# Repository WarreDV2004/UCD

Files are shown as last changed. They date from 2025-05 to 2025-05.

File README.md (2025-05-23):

# VibeLink
*Kotstudenten gemakkelijker laten communiceren met mede kotstudenten.* 

*Projectteam: Cezar Herbots; Warre De Vriendt*

Datum: 22/05/2025

## Samenvatting

Kotstudenten komen vaak toe op kot zonder iemand te kennen. Velen durven andere studenten niet snel aan te spreken en zo kunnen ze zich na een tijd eenzaam voelen. De oplossingen hiervoor is VibeLink een product dat niet alleen sfeer toevoegt aan je kot, maar vooral op een laagdrempelige manier je gevoel kan weergeven en overbrengen naar de medekotstudenten. Hiermee kunnen andere studenten jouw mood zien en jij hun mood.

"VibeLink moet studenten op het juiste moment een subtiel duwtje geven om verbinding te maken, zonder frictie of sociale druk."

<div align="center">

<table>
  <tr>
    <td rowspan="2">
      
    </td>
    <td>
      
    </td>
  </tr>
  <tr>
    <td>
      
    </td>
  </tr>
</table>

</div>

## Introductie

In veel studentenkoten is de inrichting gericht op individuele kamers en privacy, wat er vaak toe leidt dat studenten elkaar minder spontaan ontmoeten of met elkaar in contact komen. Dit blijkt ook uit verschillende artikelen. Met VibeLink willen we de sociale drempel verlagen en studenten stimuleren om vaker met elkaar te communiceren.

De kernfunctie van VibeLink is het delen van gemoedstoestanden en intenties met medebewoners. Studenten kunnen eenvoudig aangeven hoe ze zich voelen of waar ze zin in hebben, met opties zoals:

- Samen koken
- Samen sporten
- Iets gaan drinken
- Niet storen / slaapstand
- Nerveus
- Blij
- Verdrietig

De gebruiker behoudt hierbij volledige controle over wanneer en welke mood hij of zij deelt met anderen.

Naast deze communicatiefunctie is VibeLink gekoppeld aan een slimme lamp, die de gebruiker kan plaatsen in een armatuur naar keuze. Deze lamp vergroot de zichtbaarheid en het gebruik van het systeem, en zorgt voor een visuele indicatie wanneer er een "match" is — wanneer iemand anders zich in dezelfde mood bevindt.

De bediening gebeurt via één draai-/drukknop, geïnspireerd op het bedieningsprincipe van de Google Nest Thermostaat. Hiermee kan de gebruiker:

- Een mood selecteren
- De slimme verlichting aanpassen
- Instellingen wijzigen

Op het scherm van de VibeLink wordt duidelijk weergegeven welke moods andere kotgenoten momenteel hebben gedeeld, waardoor het makkelijker wordt om contact te leggen of initiatief te nemen.

> [!Note]
> - Volledige protocollen en reports zijn beschikbaar onderaan de pagina bij [bijlagen](https://github.com/WarreDV2004/UCD/edit/main/README.md#bijlagen).
> - Ruwe data zoals foto's en notities zijn terug te vinden in de protocollen en reports.
> - Alle geraadpleegde bronnen zijn beschikbaar onderaan de pagina bij [bronnen](https://github.com/WarreDV2004/UCD/edit/main/README.md#bronnen).
> - Code en CAD modellen zijn terug te vinden in de desbetreffende mappen.

## Methodologie

Het proces startte met een verkennende fase, waarin de probleemstelling kritisch werd onderzocht. Centrale vragen waren: Wat is het probleem? Is het daadwerkelijk een probleem? En in hoeverre kan dit onderbouwd worden met bestaand of nieuw onderzoek? Na een herdefiniëring van de oorspronkelijke opdracht (“Rip the Brief”) werd de volgende design challenge geformuleerd:
Hoe kunnen slimme producten ingezet worden om emoties tussen kotstudenten op een laagdrempelige manier met elkaar te communiceren?

Tijdens de ontdekkingsfase werd onderzoek verricht naar het thema eenzaamheid onder studenten. Literatuurstudie en enquêtes onder kotstudenten gaven inzicht in de schaal en relevantie van het probleem, zowel algemeen als binnen de directe doelgroep. De resultaten bevestigden dat sociale isolatie op kot een herkenbaar en actueel probleem vormt. Deze bevindingen dienden als basis voor het definiëren van een gerichte ontwerpuitdaging.

Aan de hand van een full day sprint werden verschillende oplossingsrichtingen gegenereerd. Deze concepten zijn geëvalueerd op haalbaarheid, impact en gebruiksvriendelijkheid. Op basis van deze analyse werd één concept geselecteerd voor verdere uitwerking.

In de definitiefase werd onderzocht welke aanvullende functies het product kon bevatten om de betrokkenheid te verhogen. Een voorbeeld hiervan is de koppeling met een slimme lamp, die zowel de zichtbaarheid als het gebruik stimuleert. Daarnaast werden diverse interactie- en bedieningsmodellen onderzocht om tot de meest intuïtieve gebruikerservaring te komen.

De ontwikkelfase bestond uit drie delen, telkens met een specifieke focus op een vorm van ergonomie:

Develop 1: Fysieke en sensoriële ergonomie, getest via Wizard of Oz-methodes en touch and feel-materialen.

Develop 2: Integratie in het dagelijkse leven van studenten, onderzocht aan de hand van storyboards en contextuele toepassingen. Integratie in de gebouwen, interviews met verhuurders.

Develop 3: Cognitieve en deels sensoriële ergonomie, met nadruk op interfaceontwerp en gebruikslogica.

Elke fase droeg bij aan de ontwikkeling van een functioneel en gebruiksvriendelijk prototype dat gericht is op het versterken van sociale verbondenheid binnen studentenomgevingen.

Op het einde volgt de delivery en de eindpresentatie van het proces.

Afbeelding 2

## Discovery

### Doelstellingen

Tijdens deze ontdekkingsfase proberen we een helder beeld te krijgen van het probleem en hoe dit op te lossen. Door een goed zicht te hebben op het probleem en de bestaande oplossingen voor dit probleem kan er gekeken worden naar opportuniteiten voor een oplossing. Om het probleem scherp te stellen wordt er gebruik gemaakt van enquêtes en benchmarks. Een helder geformuleerde "how might we" bekomen is hier cruciaal in.

### Materiaal & methoden
* Enquêtes via Google Forms
* Benchmarks

Het uitvoeren van de enquête is bedoeld om een beter beeld te krijgen op het probleem om hier dan ook een zo goed mogelijke oplossing te vinden. 

Voor de benchmarks is er online gezocht naar 2 verschillende producten. Aan de ene kant wordt er gezocht naar bestaande producten die een oplossing bieden voor ons probleem en langs de andere kant wordt er gezocht naar bestaande manieren die helpen bij het communiceren van emoties bij anderen.

### Resultaten
#### Benchmarks (N=6)

Bij het analyseren van bestaande oplossingen voor het probleem van eenzaamheid, blijkt dat de meeste producten en systemen zich niet specifiek richten op studenten. Er bestaan oplossingen in twee hoofdvormen: domoticasystemen en digitale applicaties, zoals dating- en vriendenapps.

Domotica-oplossingen of AI-gestuurde gezelschapssystemen zijn vaak gericht op het vervangen van sociaal contact door technologie, zoals virtuele assistenten of sociale robots. Dit strookt echter niet met de gewenste richting van het project. De intentie is niet om technologie als vervanging van menselijk contact te gebruiken, maar om het menselijke contact te faciliteren en versterken — studenten dichter bij elkaar brengen in plaats van dichter bij hun scherm.

Wat betreft digitale applicaties zijn er tal van oplossingen, vooral in de vorm van dating- of sociale netwerkapps. Hoewel een app niet als eindproduct wordt overwogen, bieden deze platformen wel relevante inzichten. Veel van deze apps werken via wederzijdse bevestiging (bijvoorbeeld door swipen), waarbij communicatie pas mogelijk wordt als beide partijen interesse tonen. Dit mechanisme verlaagt de drempel tot contact, omdat het risico op afwijzing wordt geminimaliseerd. Het bevordert zelfvertrouwen en vergemakkelijkt de eerste stap tot sociale interactie — een principe dat waardevol is bij het ontwerpen van een fysieke, sociaal ondersteunende oplossing.

Op het vlak van emotiecommunicatie zijn er enkele gezelschapsspellen ontwikkeld, voornamelijk gericht op kinderen, die emoties op een toegankelijke manier trachten over te brengen. Deze spellen maken veelvuldig gebruik van kleur als communicatiemiddel. Ondersteunend onderzoek toont bovendien aan dat kleuren specifieke emoties kunnen oproepen of versterken. Hieruit kan worden afgeleid dat het gebruik van kleur een effectieve en intuïtieve methode is voor het visueel overbrengen van gemoedstoestanden. Deze inzichten vormen een belangrijke onderbouw voor het verdere ontwerp van de communicatievormen binnen het project.

#### Enquête (N=13)
Uit de Enquête blijkt dat studenten minder geïnteresseerd zijn in het communiceren van echte emoties maar dat ze eerder moods zouden willen communiceren. Ook blijkt er dat er maar een kleine hoeveelheid van de mensen zich daadwerkelijk eenzaam of verdrietig voelt op kot maar dat een grote hoeveelheid van de mensen (ongeveer 75%) hun kotgenoten meer wilt zien en meer met hun in contact willen staan. Het doel van het product moet dus meer gefocust zijn op het communiceren van moods zoals samen iets gaan drinken en minder op emoties zoals verdrietig voelen.

### Conclusies & implicaties
Uit de resultaten van de twee onderzoeken kunnen er een paar design requirements opgesteld worden die moeten meegenomen worden bij het ontwerpen van het product.

> **Important**
> 
> Design Requirements:
> - **D4.1** Het product communiceert de emoties aan de hand van kleur.
> - **D4.2** Het product communiceert vooral moods. 

## Definition
In deze fase wordt er verder gedefinieerd hoe de oplossing van het probleem word uitgewerkt. Het is belangrijk om hier nauw met de mogelijke gebruikers samen te werken en geen assumpties te maken.
Er is gekozen om in 2 waves van prototypes te werken. De eerste wave focust vooral op de concept validation, maar ook op de vorm en de extra functie die er bij komt zoals: sfeerverlichting, muziekspeaker of hanglamp. Bij de tweede wave wordt er onderzocht welke lay-out van knoppen en lichtjes het meest geschikt is om de stemmingen van de medestudenten weer te geven. Ook is er gevraagd welke moods de gebruikers willen kunnen weergeven en hoe dit weergegeven moet worden.

### Doelstellingen
Na deze fase wordt in kaart gebracht hoe het product eruit zal zien en welke functies het zal hebben. Daarnaast worden een [storyboard](https://github.com/user-attachments/assets/4796fb20-8204-4eef-a8bf-d4916b57c2e5)  en een render opgesteld om het geheel te verduidelijken.

### Materiaal & methoden
Om de doelstellingen te bereiken, werden verschillende prototypes en testmethoden ingezet. Kartonnen prototypes dienden voor snelle conceptverkenning, terwijl 3D-geprinte modellen fysieke eigenschappen evalueerden. Verwisselbare papieren interfaces maakten flexibele interface-tests mogelijk. User interviews brachten inzichten in behoeften en verwachtingen, waarna user testing de gebruiksvriendelijkheid en functionaliteit beoordeelde. Deze aanpak bood een diepgaand inzicht in de gebruikservaring en de haalbaarheid van het ontwerp.

In de eerste wave wordt het initieel idee gevalideerd bij potentiële gebruikers. Basis prototypes uit karton gaven de gebruikers een beter idee over wat het gaat en hoe het er potentieel zou kunnen uitzien. Er werden 4 verschillende prototypes gemaakt die ook telkens een andere extra functie kregen, zo konden we ook aftoetsen welke extra functie geprefereerd wordt.

In de tweede wave wordt er getoetst naar de hoeveelheid knoppen, de functie ervan en daarbij ook de lay-out. Dit werd gedaan door verschillende lay-outs te ontwerpen in Affinity Designer en deze af te drukken. Zo is het mogelijk om met één basisvorm verschillende lay-outs te testen. Voor deze basisvorm hebben we gekeken naar de resultaten van wave 1.
  
### Resultaten
#### Wave 1 (N=5)

Hieronder is het eerste prototype te zien. Hierbij is de extra functie sfeerverlichting. Al snel bleek uit de testen dat gebruikers het te groot vonden. Het idee van sfeerverlichting op kot vonden ze wel positief.

<div style="display: flex; justify-content: center; gap: 10px; align-items: center; margin: 20px 0; width: 100%;">
  Afbeelding 1
  Afbeelding 2
</div>

Het tweede prototype was een hanglamp. Mensen vonden deze ook te groot, maar vooral niet zo praktisch aangezien het aan het plafond hangt en wat minder toegankelijk is.

<div style="display: flex; justify-content: center; gap: 10px; align-items: center; margin: 20px 0; width: 100%;">
  Afbeelding 1
  Afbeelding 2
</div>

Het derde prototype was een muziekspeaker. Mensen vonden het ontwerp van het prototype wel zeer goed en het idee van een speaker erbij te hebben leek hun ook wel tof.

<div style="display: flex; justify-content: center; gap: 10px; align-items: center; margin: 20px 0; width: 100%;">
  Afbeelding 1
  Afbeelding 2
</div>

Het laatste prototype was veel kleiner dan de andere en had geen extra functie. Deze dient dus puur om de moods te zien en je eigen mood over te brengen. De testers hielden wel van de kleinere vormfactor, maar vonden de prototypes met een extra functie toch aantrekkelijker. 

<div style="display: flex; justify-content: center; gap: 10px; align-items: center; margin: 20px 0; width: 100%;">
  Afbeelding 1
  Afbeelding 2
</div>

De gebruikers zelf vonden het concept zelf ook goed, al merkten ze wel op dat het nadat ze hun medekotstudenten beter kennen, het vervangen zou kunnen worden door de smartphone. Het is dus belangrijk om de focus te leggen op het gebruiksgemak ervan zodat het toch eerder zal blijven gebruikt worden dan de smartphone.

#### Wave 2 (N=5)

Hieronder is de eerste basisvorm te zien. Dit is dezelfde vorm als bij het prototype van de sfeerlamp, maar kleiner.

Afbeelding 2

Er is ook een tweede basisvorm gemaakt om te variëren op het idee van een sfeerlamp. Deze was eerst in karton, wat niet sterk genoeg was. Daarna werd deze ge-3D print.

<div style="display: flex; justify-content: center; gap: 10px; align-items: center; margin: 20px 0; width: 100%;">
  Afbeelding 1
  Afbeelding 2
</div>

Hieronder zijn de verschillende layouts te zien voor beide basisvormen. Er is gevarieerd op: waar het licht te zien is, waar de knoppen staan, de hoeveelheid knoppen en de soort knop. Met zaken zoals de grootte van de ledjes, hoe de kotgenoten worden weergeven of de vorm van de knop, is nog geen rekening gehouden.

<div style="display: flex; justify-content: center; gap: 10px; align-items: center; margin: 20px 0; width: 100%;">
  Licht onder
  knop zijkant
  Afbeelding 2
</div>
<div style="display: flex; justify-content: center; gap: 10px; align-items: center; margin: 20px 0; width: 100%;">
  
  
  Afbeelding 2
</div>
<div style="display: flex; justify-content: center; gap: 10px; align-items: center; margin: 20px 0; width: 100%;">
  Licht onder
  Afbeelding 2
</div>

Met al deze verschillende lay-outs konden de testpersonen zelf spelen met mogelijke combinaties die zij het beste vonden. De voorkeur voor de basisvorm ging meestal naar het kleine prototype. Dit met één knop vanboven die beide functies kan bedienen, het dimmen van het sfeerlicht en je mood aanduiden. 

In de tweede wave is onderzocht welke moods gebruikers graag op het product willen zien. Hiervoor kregen zij een lijst met verschillende emoties, omdat het moeilijk is om spontaan op een gevarieerd aantal emoties te komen. Recognition over recall. De gebruikers mochten dan 5 emoties aanduiden op het blad en ook nog 2 extra functies/emoties zelf opschrijven zoals sporten of koken.

Afbeelding 2

Hier is dan uit gebleken dat volgende emoties het vaakst werden gokozen:
- Slaapstand/niet storen/uit
- Sporten
- Iets gaan drinken
- Koken
- Verdrietig
- Blij
- Nerveus/geïrriteerd

Bij elke mood wordt er ook een gepast kleur gekozen aan de hand van Plutchik's Wheel of Emotions
- Slaapstand/niet storen/uit:  zwart, zodat er geen extra licht in de kamer brand.
- Sporten: groen, wordt gelinkt aan submission, de overgave aan de sport.
- Iets gaan drinken:  bordeauxrood, wordt gelinkt aan de avondsfeer en een contrast met de andere kleuren.
- Koken: oranje, wordt gelinkt aan intresse.
- Verdrietig: blauw, wordt gelinkt aan sadness.
- Blij: geel, wordt gelinkt aan joy.
- Nerveus/geïrriteerd: magenta, wordt gelinkt aan remorse.

Plutchik's Wheel of Emotions

Wheel of emotions

### Conclusies & implicaties
#### Wave 1 (N=5)
Uit de eerste wave bleek dat het product compact moest zijn en subtiel, liefst als een sfeerlicht. Ook moet het simpel blijven met niet te veel knoppen. De kleur van het sfeerlicht moet ook niet hetzelfde zijn als de kleur van de mood waar ze zelf in zitten. Ook werd er aangegeven dat het wel gemakkelijk zou zijn als er een indicatie is als er iemand in dezelfde mood zit.
>"Het zou wel handig zijn als er wordt aangegeven als iemand in dezelfde mood zit, want je zit waarschijnlijk niet de hele tijd ernaar te kijken." Linde, 19, Student

> **Important**
> 
> Design Requirements:
> - **D1.1** Het product is compact, maximum 20x20x20 cm.
> - **D1.2** Het product geeft een indicatie als er een match is. 
> - **D2.1** De kleur van het sfeerlicht is onafhankelijk van de soort mood.  

#### Wave 2 (N=5)
Uit de tweede wave is gebleken welke moods er op het product moeten komen. Ook welke functies er door hoeveel knoppen moeten worden bediend en waar deze terecht komen. Dit op de kleinere vorm. Hieronder is een foto te zien van het gekozen prototype met de meest gekozen lay-out.

Afbeelding 2

> **Important**
> 
> Design Requirements:
> - **D3.1** Het product heeft 1 knop die de verschillende functies bediend.
> - **D4.2** Volgende moods staan op het product: Slaapstand/niet storen/uit, Sporten, Iets drinken, Koken, Verdrietig, Blij, Nerveus/geïrriteerd?

Hieronder is dan de render te zien van hoe het eruit zou kunnen zien.

<div style="display: flex; justify-content: center; gap: 10px; align-items: center; margin: 20px 0; width: 100%;">
  Afbeelding 1
  Afbeelding 2
</div>

## Develop 1: fysieke en sensoriële ergonomie (N=4)

### Doelstellingen
Om het product gebruiksvriendelijker te maken, is inspiratie gehaald uit de intuïtieve bediening van de Google Nest-thermostaat. Het concept omvat een tweedelige opzet: een hoofdmodule waarmee gebruikers hun mood kunnen instellen, de moods van kotgenoten kunnen bekijken en het sfeerlicht kunnen bedienen. En een slimme lamp, vergelijkbaar met de Philips Hue, die gekoppeld is aan de hoofdmodule. Hierdoor kan de gebruiker de verlichting aanpassen aan de gewenste sfeer en optimaal laten aansluiten bij het interieur.
Eenderzijds wordt er een concept validation gedaan voor het nieuwe concept, meer er wordt ook getest naar de fysieke en sensoriele ergonomie. Met als doel te weten te komen welke eindoplossing het aangenaamste is voor de studenten.

### Materialen & Methoden
Om de functionaliteit te testen, wordt het Wizard of Oz-principe toegepast. Er wordt een ge-3D printed prototype gebruikt met de algemene vorm en de draai ring. Hiernaast is er een arduino met een potentiometer verbonden met de laptop, deze is in verbinding met protopie conect. Daarnaast wordt er ook een slimme lamp verbonden met de smartphone van een onderzoeker. Wanneer een tester een handeling uitvoert op de module, wordt dezelfde actie door de onderzoeker op de potentiometer en smartphone uitgevoerd. Hierdoor ontstaat de indruk dat de tester de interface en de lamp rechtstreeks via het prototype bedient, waardoor realistische gebruikerservaringen kunnen worden geobserveerd.

<details>
  <summary>Klik hier om de Arduino-code te bekijken.</summary>

  ```cpp
  int intensiteits_pin = A0; 

  void setup() {
      pinMode(intensiteits_pin, INPUT); // INPUT_PULLUP is niet nodig voor een potentiometer
      Serial.begin(9600);
  }

  void loop() {
      int intensiteits_waarde = analogRead(intensiteits_pin); 
      Serial.print("Intensiteit|| ");
      Serial.println(intensiteits_waarde);
      delay(500);
  }
```
</details> 

<div style="display: flex; justify-content: center; gap: 10px; align-items: center; margin: 20px 0; width: 100%;">
  
  
</div>

Om de fysieke ergonomie te onderzoeken wordt er eerst een [antropometrische studie](https://docs.google.com/document/d/151swEXQBkQlyvM8BVWTO21OE8UqdC8CK/edit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) gedaan, waar bij de testen deze waarden worden voorgelegd en feedback wordt gevraagd een de testers. Voor de sensoriele ergonomie te testen worden er voorbeelden van visuele en auditieve feedback voorgelegt en wordt er gevraagd naar feedback en eigen input. Voor het tactiele gedeelte is er een touch and feel bord gemaakt met verschillende texturen op, die de buitenring zou aannemen. Hier wordt er een ranking in gemaakt.

<div style="display: flex; justify-content: center; gap: 10px; align-items: center; margin: 20px 0; width: 100%;">
  
</div>

De volgende structuur is gehanteerd voor het interview en is tevens terug te vinden in het protocol. Het interview begon met een korte samenvatting van het voorafgaande onderzoek. Vervolgens werd het nieuwe concept toegelicht, waarna de eerste reacties hierop werden besproken.

Daarna werd een scenario gepresenteerd waarin de student thuiskomt op kot, het Wizard of Oz-principe werd hier toegepast. Tussen de conceptuitleg en het scenario werden aanvullende vragen gesteld over de fysieke ergonomie. Tot slot kwamen vragen over de sensoriële ergonomie aan bod, waaronder: visueel, auditief en tactiel.

Het interview werd afgesloten met een samenvatting van de belangrijkste bevindingen.

### Resultaten

De reacties op het nieuwe concept waren positief. Veel deelnemers ervaarden zowel de vorm als de functionaliteit als aangenamer en gebruiksvriendelijker. Dit bevestigt voor ons dat we een belangrijke stap in de juiste richting zetten wat betreft de vormgeving van ons eindproduct.

Ook met betrekking tot de werking en de bedieningswijze werd snel duidelijk dat het concept effectief functioneert.

De meerderheid van de studenten vond de grootte van de diameter goed, al kunnen de afmetingen van het product later nog veranderen wegens het gebruik van standaard elektronica.
Uit de testen zijn we op het idee gekomen het apparaat magnetisch aan de muur te laten bevestigen. Hierdoor kan de gebruiker bij installatie zelf kiezen hoe hoog hij het apparaat hangt. We raden schouderhoogte aan, wat uit de antropometrische stude ongeveer 140 cm bleek te zijn. Bij de tester was het gemiddelde ongeveer 145 cm.

<div style="display: flex; justify-content: center; gap: 10px; align-items: center; margin: 20px 0; width: 100%;">
  
</div>

Uit de tests bleek dat de bediening als zeer intuïtief werd ervaren. De draairichting voelde natuurlijk aan en werd zonder moeite correct geïnterpreteerd. Wel werd opgemerkt dat het indrukken van het apparaat verduidelijking behoeft, bijvoorbeeld door een visuele of tactiele aanduiding, om de werking volledig eenduidig te maken.

Uit de vragen over visuele feedback bleek dat meldingen voornamelijk via de aangesloten lamp zouden plaatsvinden. De lamp zou enkele keren knipperen en daarna stoppen. Indien er geen interactie met het apparaat plaatsvindt, zou de lamp na 10 à 15 minuten opnieuw knipperen. Blijft interactie daarna uit, dan verandert de status niet verder. Daarnaast zou het apparaat zelf een visuele indicatie tonen met de naam van de persoon waarmee een match is.

De meningen over auditieve feedback waren sterk verdeeld. Wat duidelijk naar voren kwam, is dat indien geluiden worden geïntegreerd in het ontwerp, zowel het volume als de geluidstoon instelbaar moeten zijn. De meeste gebruikers gaven aan de voorkeur te hebben om het geluid naar wens te kunnen aanpassen of volledig uit te schakelen.

Voor de tactiele test konden deelnemers een persoonlijke top drie kiezen uit verschillende structuren. De meest gekozen opties waren: de ribbels die al op het apparaat aanwezig waren (8), hoekige ribbels voor extra grip (9), de zwarte kunststof met gestructureerd oppervlak (3).

### Conclusies & Implicaties

De belangrijkste zaken dat uit deze fase zijn gekomen zijn: dat de testers het nieuwe concept beter vinden dan ervoor, de gekozen diameter op fysiek ergonomisch vlak goed is, dat de manier van selecteren door de ring in te duwen niet zo intiutief is en dat er gekozen visuele, auditieve en tactiele feedback is.

> **Important**
> 
> Design Requirements:
> - **D5.1** Het wordt aangeraden om het op een hoogte van 1m45 te installeren.
> - **D5.2** De structuur op de buitenste ring is nummer 8 van het touch & feel board.
> - **D5.3** Het product is voorzien van een visuele en auditieve feedback.
> - **D2.2** De lamp die verbonden is flikkert zacht bij een match.
> - **D1.3** Wanneer er geen interactie is met het apparaat, 10 minuten na de match, volgt er weer een notificatie.
> - **D1.4** Het scherm op het product geeft de naam waarmee de match is weer.
> - **D1.5** De gebruiker heeft eigen vrijheid bij het instellen van de soort notificatie betreffende licht en geluid.
> - **D1.6** Het product moet worden ingeduwd na een match.
> - **D1.7** Het product is voorzien van een hub waar het apparaat kan in staan, om te bedienen als het niet aan een muur hangt.
> - **D1.8** Het product wordt bevestigd via magneten.

## Develop 2: Integratie van het product bij de gebruiker

### Doelstellingen
In deze fase ligt de focus op het gedetailleerd in kaart brengen van de volledige gebruikersreis. Dit heeft als doel eerdere assumpties te valideren en potentiële knelpunten in het concept en ontwerp te identificeren en elimineren. Daarnaast wordt ook de tweede belangrijke stakeholder, de kotbazen, betrokken bij het proces. Het concept wordt aan hen voorgelegd om waardevolle feedback te verzamelen. Zij zouden tevens de Vibelinks aanschaffen als extra voorziening voor hun koten en instaan voor de installatie ervan.

### Wave gebruikers (N=4)

Onderzoeksvragen: "Wat kan er aangepast worden zodat de vibelink een standaard onderdeel wordt van de gebruikersreis doorheen de dag?" en "Door welke triggers gebeurt dit en welke beloning heeft dat achteraf?"

#### Materialen & Methoden

Tijdens de interviews met de testpersonen werden verschillende situaties voorgelegd, zoals: "Je hebt de hele dag geen les en het is mooi weer" of "Je hebt een volledige dag les tot 18 uur". De deelnemers werd gevraagd om zo gedetailleerd mogelijk de meest gebruikelijke gang van zaken te beschrijven, van het opstaan in de ochtend tot het slapengaan in de avond.
De antwoorden werden vervolgens geanalyseerd om terugkerende patronen te identificeren. Per situatie werd een onderverdeling gemaakt in ochtend, middag, namiddag en avond. Op basis hiervan zijn zes scènes opgesteld, die met behulp van generatieve AI werden uitgewerkt tot een storyboard.

De vijf situaties zijn als volgt:
1) Je staat 's morgens op en hebt heel de dag geen les. Je hebt weinig tot geen schoolwerk te doen.
2) Je staat 's morgens op en hebt heel de dag geen les. Je hebt veel schoolwerk te doen.
3) Je komt 's middags terug van de les en het is goed weer buiten.
4) Je komt 's middags thuis van de les en het is slecht weer buiten.
5) Je komt 's avonds thuis na de les.

#### Resultaten

Hieronder zijn de gevormde storyboards, van de verschillende situaties, op volgorde te zien:

<div style="display: flex; justify-content: center; gap: 10px; align-items: center; margin: 20px 0; width: 100%;">
  Storyboard 1
</div>

1) Ochtendrust – Studenten slapen meestal uit tot 10 à 11 uur, starten daarna hun dag op eigen tempo.
2) Actieve voormiddag – Wandelen of fietsen wordt vaak bewust alleen gedaan, zonder afspraken.
3) Lunchmoment – Een snelle, eenvoudige maaltijd; soms met een gevoel van doelloosheid of planningstress.
4) Namiddagactiviteit – Tijd met vrienden op café of terras; anders alleen films of series kijken.
5) Avondeten – Er wordt gekookt, soms samen, soms bewust alleen voor rust of gemak.
6) Avondontspanning – Studenten ontspannen alleen of gaan uit met vrienden.

<div style="display: flex; justify-content: center; gap: 10px; align-items: center; margin: 20px 0; width: 100%;">
  Storyboard 2
</div>

1) Ochtendroutine – Studenten staan vroeg op, ontbijten en bereiden zich voor op een studiedag.
2) Studielocatie – Er wordt gestudeerd in de bibliotheek of op kot aan het bureau.
3) Middagmaal – Een snelle lunch met boterhammen of een broodje, vaak alleen.
4) Namiddagstudie – Studeren wordt verdergezet; op kot is er meer afleiding via de smartphone.
5) Avondstudie of rust – Sommigen werken verder, anderen ontspannen achter de laptop.
6) Eenvoudige avondmaaltijd – Er wordt simpel gekookt door vermoeidheid na een lange studiedag.

<div style="display: flex; justify-content: center; gap: 10px; align-items: center; margin: 20px 0; width: 100%;">
  Storyboard 3
</div>

1) Ochtend – Studenten staan op, maken zich klaar en gaan naar de les.
2) Middag – Er wordt op school gegeten, vooral als er in de namiddag nog les is.
3) Na de les – Studenten spreken af met klasgenoten om iets te drinken of te ontspannen.
4) Kot & boodschappen – Sommigen gaan eerst naar kot en doen samen boodschappen.
5) Avond – Er wordt samen gekookt of uitgegaan, of men werkt verder aan schooltaken.

<div style="display: flex; justify-content: center; gap: 10px; align-items: center; margin: 20px 0; width: 100%;">
  Storyboard 4
</div>

1) Ochtendroutine – Studenten staan op, maken zich klaar en vertrekken naar de les.
2) Lunchmoment – Er wordt op school gegeten of snel iets klaargemaakt op kot, zoals boterhammen.
3) Namiddagrust – Eerst wordt er gerust, gevolgd door schoolwerk indien nodig.
4) Vrije tijd – Bij geen schoolwerk: videobellen, plannen, gamen of series kijken.
5) Avondeten – Studenten koken alleen of samen en eten op kot.
6) Avondafsluiting – Na het opruimen wordt er ontspannen en klaargemaakt voor het slapengaan.

<div style="display: flex; justify-content: center; gap: 10px; align-items: center; margin: 20px 0; width: 100%;">
  Storyboard 5
</div>

1) Terug naar kot – Na de les keren studenten terug naar hun kamer.
2) Avondeten – Ze bereiden snel iets eenvoudigs, vaak boterhammen, wegens vermoeidheid.
3) Avondafsluiting – Er wordt opgeruimd, gerust en voorbereid op het slapengaan.

### Wave kotbazen (N=3)

#### Materialen & Methoden

<div style="display: flex; justify-content: center; gap: 10px; align-items: center; margin: 20px 0; width: 100%;">
  Storyboard 5
</div>

Als onderzoeksmethode bij de kotbazen wordt er gekozen om interviews af te nemen. Tijdens het interview wordt het project kort toegelicht zodat de respondenten een duidelijk beeld krijgen van de doelstellingen en de context. Vervolgens worden gerichte vragen gesteld om de mate van interesse in het project te peilen.

Een belangrijk onderdeel van het interview is het achterhalen of de kotbazen bereid zouden zijn te investeren in het voorgestelde product, en welke drempelwaarden of voorwaarden zij hierbij hanteren. Aangezien de aanschaf en installatie van het product onder de verantwoordelijkheid van de kotbazen zouden vallen, wordt eveneens onderzocht welke vereisten zij stellen aan de installatie.

Daarnaast wordt tijdens het interview in kaart gebracht welke factoren een positieve dan wel negatieve invloed hebben op hun beslissing om het product aan te schaffen. Tot slot wordt er nagegaan welke elementen bepalend zijn voor de prijszetting vanuit het perspectief van de kotbazen.

#### Resultaten

Uit de interviews kwamen enkele essentiële requirements naar voren. Zo moet het product een duidelijke meerwaarde bieden voor het kot. Het wordt aantrekkelijker voor kotbazen om in het product te investeren wanneer er effectief vraag naar is vanuit studenten, of wanneer het product een extra kwaliteitslabel aan het kot toevoegt – vergelijkbaar met voorzieningen zoals een airco. Dit stelt hen in staat om de huurprijs lichtjes te verhogen, waardoor de investering zich op termijn kan terugverdienen.

Voor de prijsbepaling is het belangrijk om met een eenmalige aankoop te werken. De kotbazen gaven aan dat ze minder snel gaan investeren in een product met abonnement dan in een product met een eenmalige aankoop.

Wat betreft de installatie in de kamer is het belangrijk dat er geen blijvende schade aan het interieur ontstaat. De stroomvoorziening dient bij voorkeur via een standaard stopcontact te verlopen, zodat er geen breekwerken of extra bekabeling nodig zijn. Voor het bevestigen van het muurplaatje wordt aangeraden om gebruik te maken van verfvriendelijke dubbelzijdige tape, zodat de muur intact blijft bij eventuele verwijdering.

### Conclusies & Implicaties

#### Wave gebruikers

Er zijn duidelijke terugkerende momenten waarop studenten tijd en mentale ruimte hebben om stil te staan bij hun dag en eventueel iets te delen via VibeLink. Deze momenten doen zich vooral voor in de ochtend, wanneer er nog weinig verplichtingen zijn; in de middag, wanneer er nog geen concrete plannen zijn en studenten zoeken naar een invulling van hun dag; en in de avond, na het eten, wanneer er een rustmoment ontstaat en studenten zich meer openstellen voor reflectie en sociaal contact. Op deze momenten kan de interactie uitgelokt worden door bijvoorbeeld een melding.

Bepaalde triggers die studenten ertoe kunnen aanzetten om VibeLink te gebruiken zijn: momenten van twijfel zoals "Wat ga ik nog doen?", de invloed van weersomstandigheden, de behoefte aan sociaal contact gecombineerd met een angst voor afwijzing, en de behoefte aan rust.
De bijbehorende beloningen zijn onder andere het gevoel van verbondenheid, momenten van rust, een gevoel van controle, en de voldoening om iets betekenisvols te hebben gedaan tijdens de dag.
Daarnaast kunnen ook actieve triggers worden toegevoegd door op strategische momenten meldingen te versturen en gebruikers te belonen, bijvoorbeeld door badges of streaks toe te kennen voor het consequent doorgeven van hun stemming over meerdere dagen.

Dit valt ook te linken aan Foggs 3 core motivaters, namelijk: seek pleasure and avoid pain, seek hope and avoid fear en seek social acceptance and avoid rejection.

De student zit ook vaak aan zijn bureau of in bed, de mogelijkheid om VibeLink modulair te maken kan dus zeker een meerwaarde bezorgen.

> **Important**
>
> Design Requirements:
> - **D6.1** Het product verwelkomt de student als die in de buurt komt.
> - **D6.2** Het product geeft op verschillende momenten van de dag een gepaste boodschap om een interactie uit te lokken.
> - **D5.4** Er is een hub om de VibeLink op een zelfgekozen plaats te zetten.

#### Wave kotbazen

Uit de interviews met de kotbazen kunnen er op 2 vlakken conclusies genomen worden:

Prijs:
Voor de prijsbepaling van het product is het belangrijk dat het product een zekere meerwaarde geeft aan het kot. Het product moet verkocht worden als een eenmalige aankoop om abonnementen en prijsstijgingen te vermijden. 

Bevestiging:
Bij het bevestigen van het product is het zeer belangrijk dat er geen schade wordt aangericht aan de kamer. Als stroomvoorziening wordt er best gebruik gemaakt van een stopcontact. De hub zou verbonden zijn met het stopcontact om zo het apparaat op te laden. Voor het ophangen van het muurplaatje wordt er best dubbelzijdige tape gebruikt, er zou gebruik gemaakt worden van dubbelzijdige tape die bedoeld is om op muren te plakken om het meekomen van verf te vermijden. Moest de student het apparaat nog willen verplaatsen kan dit door het muurplaatje op een andere locatie te hangen met een nieuw stuk tape, zo kunnen onnodige gaten in de muur vermeden worden.

> **Important**
>
> Design Requirements:
> - **D5.5** De bevestiging aan de muur is aan de hand van dubbelzijdige tape en magneten.
> - **D5.6** Er is een aparte hub waar het product op gedokt kan worden om op te laden.
> - **D1.9** Het product is een investering voor verhuurders die ze in de huurprijs kunnen doorrekenen.

## Develop 3: cognitieve ergonomie (N=5)

### Doelstellingen

In deze derde en laatste fase van de ontwikkelingscyclus ligt de focus op de interactie tussen de gebruiker en de interface van de Vibelink. Het doel is om inzicht te krijgen in de gebruiksvriendelijkheid en effectiviteit van het systeem. Daarbij wordt er onderzocht hoe de cognitieve belasting voor de gebruiker tot een minimum beperkt kan worden, of de interface eenvoudig te gebruiken is, en of alle noodzakelijke functionaliteiten duidelijk en toegankelijk zijn geïntegreerd.
Deze aspecten worden geëvalueerd aan de hand van een zo interactief mogelijk eind prototype, waarmee er realistische tests kunnen worden uitgevoerd.

### Materialen & Methoden

De gebruikerstests worden uitgevoerd met een werkend 3D-geprint prototype waarin een rotary encoder is geïntegreerd. Deze encoder is verbonden met een Arduino, die op zijn beurt gekoppeld is aan een laptop waarop de interactieve interface, ontworpen in ProtoPie, draait.

<details>
  <summary>Klik hier om de Arduino-code te bekijken.</summary>

  ```cpp
 int pinA = 3; // Connected to CLK
 int pinB = 4; // Connected to DT
 int drukknop = 5; // Conect to SW
 int encoderPosCount = 0;
 int pinALast;
 int aVal;
 int druk_teller = 0;
 int staat1;
 bool drukknop_last = HIGH;
 unsigned long lastDebounceTime = 0;
 unsigned long debounceDelay = 100;  // 100 ms debounce tijd
 unsigned long lastTurnTime = 0;
 unsigned long turnDebounceDelay = 100; // 100 ms tussen rotaties

 boolean bCW;

 void setup() {
 pinMode (pinA,INPUT);
 pinMode (pinB,INPUT);
 pinMode (drukknop, INPUT_PULLUP);
 /* Read Pin A
 Whatever state it's in will reflect the last position
 */
 pinALast = digitalRead(pinA);
 drukknop_last = digitalRead(drukknop);
 Serial.begin (9600);
}

void loop() {
    
  bool buttonState = digitalRead(drukknop);

  // Debounce controle
  if (buttonState == LOW && drukknop_last == HIGH) {
      if (millis() - lastDebounceTime > debounceDelay) {
          druk_teller++;  // Verhoog teller bij druk
          Serial.println("Drukken");
          // Serial.println(druk_teller);
          lastDebounceTime = millis(); // Reset debounce timer
      }
  }
    
  drukknop_last = buttonState; // Update vorige status

 aVal = digitalRead(pinA);
  if ((pinALast == HIGH) && (aVal == LOW)) { // Falling edge detectie
    if (millis() - lastTurnTime > turnDebounceDelay) {
     if (digitalRead(pinB) == HIGH) {
        encoderPosCount++;
        bCW = true;
        Serial.println("DraaienR");
      } else {
        encoderPosCount--;
        bCW = false;
        Serial.println("DraaienL");
      }
      lastTurnTime = millis(); // Reset debounce timer voor draai
    }
  }
  pinALast = aVal;
}
```
</details> 

<div style="display: flex; justify-content: center; gap: 10px; align-items: center; margin: 20px 0; width: 100%;">
  
</div>

Tijdens de tests wordt de gebruiker in verschillende gesimuleerde situaties geplaatst. Een voorbeeld van zo’n situatie is: "Je komt terug van de les en hebt zin om samen te koken. Geef dit aan via de VibeLink." De deelnemer wordt gevraagd om deze opdracht zelfstandig uit te voeren met behulp van het interactieve prototype.

De onderzoekers proberen zich tijdens de testmomenten zo passief mogelijk op te stellen om de spontane interactie met het prototype te observeren. Er wordt gebruik gemaakt van het think-aloud protocol, waarbij gebruikers hun gedachten en beslissingen tijdens het uitvoeren van de taak hardop verwoorden. Na afloop van de test worden aanvullende vragen gesteld over de gebruiksvriendelijkheid, de duidelijkheid van de interface en eventuele onduidelijkheden. Er wordt ook gevraagd naar gelijkaardige interfaces die de gebruiker reeds kent uit het dagelijks leven.

Er is geëxperimenteerd met verschillende prototypingvarianten, waaronder een eindig scrollmenu en een oneindig scrollmenu. Na de testscenario’s wordt het prototype vergeleken met de interface van de Google Nest, om inzichten te krijgen in de gebruikersvoorkeuren en verwachtingen. Tot slot wordt ook de voorkeur bevraagd over de fysieke interactie met de VibeLink, met name hoe gebruikers de voorkeur geven aan het schakelen tussen de wandmontage en de hub.

Hieronder is een GIF te zien van de interface in actie.



### Resultaten

De resultaten van het eindprincipe waren over het algemeen zeer positief. Er werden wel enkele verbeterpunten vastgesteld met betrekking tot de interface. De gebruikers gingen op een intuïtieve manier op ontdekking en probeerden vlot uit welke handelingen – draaien of drukken – welk effect hadden. Het werd duidelijk dat deze twee interactievormen voldoende waren om door de interface te navigeren. Toch ontstond er bij sommige testpersonen verwarring wanneer bijvoorbeeld een terugknop ontbrak, of wanneer men eerst een stemming moest aanduiden vooraleer verder te kunnen gaan in het systeem. Om de gebruiksvriendelijkheid te verhogen, zullen op deze punten gerichte aanpassingen worden doorgevoerd. Buiten de behoefte aan een terugkeerfunctie werd er geen nood ervaren aan bijkomende functionaliteiten of interfaces. Op langere termijn zouden wel extra mogelijkheden overwogen kunnen worden, zoals de koppeling met muziek of een aanduiding of het toilet bezet is.

Wat betreft de vormgeving waren de reacties overwegend positief, zowel voor de hub als voor het muurplaatje. Het bevestigingssysteem met magneten werd als bijzonder gebruiksvriendelijk ervaren. Wel werd opgemerkt dat het uitlijnmechanisme nog verder verfijnd kan worden, zodat de onderdelen gemakkelijker en nauwkeuriger met elkaar verbonden worden. 

<div style="display: flex; justify-content: center; gap: 10px; align-items: center; margin: 20px 0; width: 100%;">
  
  
</div>

### Conclusies & Implicaties

1. Gebruiksvriendelijkheid: De interface wordt grotendeels als intuïtief ervaren, maar de afwezigheid van feedback (micro-interactions) en het starten in het mood-menu in plaats van een algemeen menu veroorzaken verwarring.
2. Cognitieve belasting: Lichtintensiteitsbalkjes die vergroten en eindeloos scrollen verlagen de cognitieve belasting. Het ontbreken van visuele feedback (zoals kleurverandering per mood) verhoogt deze juist.
3. Vindbaarheid functionaliteiten: Niet alle functies zijn even makkelijk vindbaar. Dit vooral door de start in het mood menu. Gebruikers missen een centraal menu en snelle knoppen voor veelgebruikte functies (zoals licht aan/uit).
4. Verwarring of vertraging: De interface veroorzaakt vertraging door het ontbreken van navigatieopties (terugknop) en visuele indicaties. De start in het mood-menu is niet intuïtief.
5. Gebruikservaring en behoeften: Gebruikers waarderen de basisfunctionaliteit, maar missen visuele feedback en snelle toegang tot functies. Verbeterpunten zijn onder andere een centraal startscherm, visuele feedback per mood en snelle lichtbediening.

Side note: 
Het starten met het mood menu werd gedaan om de gebruiker deels te verplichten eerst hun mood door te geven zodat het gebruik hiervan maximaal is. Enerzijds wil je dat deze hoofdfunctie zo veel mogelijk gebruikt wordt, maar je wilt de gebruiker ook niet verplichten om dit te doen.
Het ontbreken van feedback door micro-interactions komt door het prototypen in ProtoPie op een bepaalde logica die hier niet toe diende om deze toe te voegen.

> **Important**
>
> Design Requirements:
>
> Interfaces:
> - **D6.3** Er is een “terug knop” te vinden in de verschillende menu’s.
> - **D6.4** Na het verwelkomen start de interfece op het basis menu.
> - **D6.5** Het product geeft feedback over de mood, als je deze selecteert.
> - **D6.6** Het product wordt gestart door te draaien of drukken.
> - **D6.7** Alle lichtwaardes moeten weergegeven worden.
> - **D4.4** Er is een neutrale mood, met wit als behorend kleur.
> - **D6.8** Kleur van eigen mood als achtergrondkleur van de VibeLink.
> - **D6.9** Bij een match past het scherm duidelijk aan om aandacht te trekken.
> - **D6.10** Feedback op het scherm bij goede bevestiging op de hub.
> 
> Hub en muurplaatje:
> - **D5.7** Volledig magnetisch aligneren van het apparaat op de hub.

### Vormstudie

Voor het renderen zijn er twee moodboard opgesteld. Eentje met een merk als referentie en eentje met een product als referentie.

<div style="display: flex; justify-content: center; gap: 10px; align-items: center; margin: 20px 0; width: 100%;">
  
  
</div>

Resultaten render:

<div style="display: flex; justify-content: center; gap: 10px; align-items: center; margin: 20px 0; width: 100%;">
  
  
</div>

<div style="display: flex; justify-content: center; gap: 10px; align-items: center; margin: 20px 0; width: 100%;">
  
  
</div>

## Conclusie
### Slotbevindingen

Het VibeLink-project is opgezet met de ambitie om de sociale cohesie in studentenhuizen op een natuurlijke en laagdrempelige manier te versterken. Door technologie in te zetten als ondersteunend middel, biedt het systeem studenten een eenvoudige manier om emoties, stemmingen en intenties te delen met hun medebewoners.

VibeLink bestaat uit drie essentiële componenten: het centrale apparaat voor moodcommunicatie en lichtbediening, een hub die draadloos opladen mogelijk maakt, en een muurplaatje dat snelle interactie bij het betreden of verlaten van de kamer faciliteert. Elk onderdeel draagt bij aan een vlot en intuïtief gebruik van het systeem.

Gedurende het project is VibeLink op regelmatige basis geëvalueerd en verbeterd, in samenwerking met studenten en huisbazen. Deze iteratieve benadering heeft geleid tot een gebruiksvriendelijke en technisch betrouwbare oplossing die inspeelt op de dagelijkse realiteit van kotstudenten.

VibeLink biedt zo een vernieuwende, subtiele en niet-intrusieve manier om sociaal contact te stimuleren binnen studentenhuizen – met technologie als brug naar meer menselijke interactie.

### Overzicht Design Requirments

| Nummer | Design Requirment | Source | Date |
|---|---|---|---|
| D1 | Algemeen | | |
| D1.1 | Het product is compact, maximum 20x20x20 cm. | Concept Validation | 30/11/2024 |
| D1.2 | Het product geeft een indicatie als er een match is. | Concept validation | 30/11/2024 |
| D1.3 | Wanneer er geen interactie is met het apparaat, 10 minuten na de match, volgt er weer een notificatie. | Develop 1 | 14/03/2025 |
| D1.4 | Het scherm op het product geeft de naam waarmee de match is weer. | Develop 1 | 14/03/2025 |
| D1.5 | De gebruiker heeft eigen vrijheid bij het instellen van de soort notificatie betrefende licht en geluid.| Develop 1 | 14/03/2025 |
| D1.6 | Het product moet worden ingeduwd na een match. | Develop 1 | 14/03/2025 |
| D1.7 | Het product is voorzien van een hub waar het apparaat kan in staan, om te bedienen als het niet aan een muur hangt. | Develop 1 | 14/03/2025 |
| D1.8 | Het product wordt bevestigd via magneten. | Develop 1 | 14/03/2025 |
| D1.9 | Het product is een investering voor verhuurders die ze in de huurprijs kunnen doorrekenen.| Develop 2 | 17/04/2025 |
| D2 | Sfeerlicht | | |
| D2.1 | De kleur van het sfeerlicht is onafhankelijk van de soort mood. | Concept Validation | 30/11/2024 |
| D2.2 | De lamp die verbonden is flikkert zacht bij een match. | Develop 1 | 14/03/2025 |
| D3 | Knoppen | | |
| D1.3 | Het product heeft 1 knop die de verschillende functies bediend. | User test Wave 2 | 24/12/2024 |
| D4 | Moods | | |
| D4.1 | Het product communiceert de emoties aan de hand van kleur. | Discovery | 29/10/2024 |
| D4.2 | Het product communiceert vooral moods. | Discovery | 29/10/2024 |
| D4.3 | Volgende moods staan op het product: Slaapstand/niet storen/uit, Sporten, Iets drinken, Koken, Verdrietig, Blij, Nerveus/geïrriteerd| User test Wave 2| 24/12/2024 |
| D4.4 | Er is een neutrale mood, met wit als behorend kleur. |Develop 3 |15/05/2025  |
| D5 | Ergonomie en vormgeving | | |
| D5.1 | Het wordt aangeraden om het op een hoogte van 1m45 te installeren. | Develop 1 | 14/03/2025 |
| D5.2 | De structuur op de buitenste ring is nummer 8 van het touch & feel board. | Develop 1 | 14/03/2025 |
| D5.3 | Het product is voorzien van een visuele en auditieve feedback. | Develop 1 | 14/03/2025 |
| D5.4 | Er is een hub om de VibeLink op een zelfgekozen plaats te zetten. | Develop 2 | 17/04/2025 |
| D5.5 | De bevestiging aan de muur is aan de hand van dubbelzijdige tape en magneten. | Develop 2 | 17/04/2025 |
| D5.6 | Er is een aparte hub waar het product op gedokt kan worden om op te laden. | Develop 2 | 17/04/2025 |
| D5.7 | Volledig magnetisch aligneren van het apparaat op de hub. | Develop 3 | 15/05/2025 |
| D6 | Interface | | |
| D6.1 | Het product verwelkomt de student als die in de buurt komt. |Develop 2 |17/04/2025  |
| D6.2 | Het product geeft op verschillende momenten van de dag een gepaste boodschap om een interactie uit te lokken.|Develop 2 |17/04/2025  |
| D6.3 | Er is een “terug knop” te vinden in de verschillende menu’s. |Develop 3 |15/05/2025  |
| D6.4 | Na het verwelkomen start de interfece op het basis menu. |Develop 3 |15/05/2025  |
| D6.5 | Het product geeft feedback over de mood, als je deze selecteert. |Develop 3 |15/05/2025  |
| D6.6 | Het product wordt gestart door te draaien of drukken. |Develop 3 |15/05/2025  |
| D6.7 | Alle lichtwaardes moeten weergegeven worden. |Develop 3 |15/05/2025  |
| D6.8 | Kleur van eigen mood als achtergrondkleur van de VibeLink. |Develop 3 |15/05/2025  |
| D6.9 | Bij een match past het scherm duidelijk aan om aandacht te trekken. |Develop 3 |15/05/2025  |
| D6.10 | Feedback op het scherm bij goede bevestiging op de hub. |Develop 3 |15/05/2025  |

## Kritische reflectie

### Semester 1

Datum: 06/01/2025

Over het algemeen zijn we tevreden over hoe ver we nu staan in het project. Het probleem waar we rond werken is ook daadwerkelijk een probleem dat rond ons bevind en wat ook in onze levens speelt. Onze oplossing heeft volgens ons hier wel een goeie invloed op. Het grootste probleem dat we ondervinden is dat we moeten zoeken dat de smartphone niet meteen ons product kan vervangen. We moeten ons product interessant genoeg houden zodat het kan blijven gebruikt worden nadat de studenten elkaar beter hebben leren kennen. Onze prototypes zijn momenteel van redelijke kwaliteit maar we zouden ze nog iets interactiever moeten kunnen maken zodat de testpersonen een nog reëler gevoel krijgen tijdens de testen. Een werkpunt is ook om meer testpersonen te interviewen zodat we meer en duidelijkere informatie bekomen.

### Semester 2

Datum: 22/05/2025

Tijdens het eerste semester volgden we voornamelijk de opgegeven structuur, waarbij de uitgevoerde testen vrij algemeen en basis waren. In het tweede semester gingen we bewuster te werk. We bepaalden concreet welke informatie nodig was om ons product verder te ontwikkelen, en voerden gerichtere en relevantere testen uit.

De eerste ontwikkelingsfase verliep bijzonder succesvol. We verzamelden veel nieuwe inzichten en bevestigingen die bijdroegen aan het verbeteren van ons concept. De tweede ontwikkelingsfase, waarin we testten met eindgebruikers, had idealiter eerder in het ontwerpproces plaatsgevonden. Veel van de bevindingen bevestigden wat we al vermoedden of reeds onbewust hadden toegepast. Toch was het waardevol om deze inzichten expliciet te kunnen onderbouwen.
De testen met kotbazen leverden dan weer verrassend waardevolle input op. Hoewel slechts drie personen deelnamen, bood het ons een ander, vaak vergeten perspectief binnen het gedeelde woonscenario. Er kwamen zo toch belangrijke aandachtspunten naar voren.

In de laatste fase werd de focus gelegd op de interface. Deze werd gebouwd in ProtoPie en bleek voldoende om bruikbare gebruikerstesten uit te voeren. Meerdere opmerkingen tijdens deze tests gingen over aspecten waar we al rekening mee hadden gehouden, maar die moeilijk volledig tot hun recht kwamen in de beperkingen van de gekozen prototypingtool.

Een logische vervolgstap zou zijn om de interface uit te werken in een geavanceerder platform dat meer controle biedt over micro-interacties en animaties. Daarnaast kunnen extra functies worden toegevoegd om via A/B-testing te evalueren welke effectief bijdragen aan gebruiksgemak en functionaliteit in een realistische context. Hoewel het product voornamelijk softwarematig blijft, zou de hardware verder kunnen worden ontwikkeld, bijvoorbeeld door een geïntegreerde printplaat en display toe te voegen, en door de connectiviteit tussen meerdere units te optimaliseren.

Over het geheel genomen kijken we tevreden terug op ons traject. We hebben waardevolle inzichten opgedaan die toekomstige ontwerptrajecten efficiënter en doelgerichter zullen maken.

De teamwerking verliep vlot dankzij directe communicatie, al was het soms lastig om gezamenlijke vrije momenten te vinden, aangezien we elk een ander leertraject volgen.

## Technische beschrijving

Onderstaande elementen zijn nodigd om het finale prototype te reconstrueren.
| Onderdeel | Prijs/extra informatie |
|---|---|
| [Arduino Uno](https://store.arduino.cc/products/arduino-uno-rev3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) | 25 euro |
| Kabeltjes | Paar eurocent|
| [Digital rotary encoder module WPI435](https://www.gotron.be/digitale-encoder.html) | 4 euro, overweeg om één van betere kwaliteit te kopen. Deze is wat gevoelig. |
| [Magneetjes](https://www.manutan.be/nl/mab/nl-vierkant-extra-sterke-magneet-a240398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) | 11 euro|
| [3D prints](https://github.com/WarreDV2004/UCD/tree/main/NX_files_en_STL_files) | 3 euro aan filament|
| Rond stuk plexieglas met diameter 65mm en dikte 3mm, preferabel zwart| Variabele prijzen |
| Ijzeren plaatje voor in hub en muurbevestiging | Zoek iets uit de afvalbak en hergebruik dit! |

De Arduino code is terug te vinden in de tekst alsook in de bijlage net als een link naar een Figma pagina waar de lay-outs van de interfaces terug te vinden zijn. De ProtoPie files zijn niet direct beschikbaar door de limitaties van de gratis versie. In de arduino code staat er welke pinnen verbonden moeten worden met welke pinnen van de rotary encoder.

De assembly-bestanden kunnen worden gebruikt als instructies om de prototypes in elkaar te zetten, al zal je waarschijnlijk deze instructies niet nodig hebben.

## Bronnen

Steadman, J. (2024, May 10). How can Higher Education end student loneliness? Unite Group. https://www.unitegroup.com/articles/higher-education-student-loneliness

1 op 3 studenten voelt zich eenzaam. (n.d.). Vrije Universiteit Brussel. https://www.vub.be/nl/nieuws/1-op-3-studenten-voelt-zich-eenzaam

“Op kot gaan is vooral ook leren balanceren” | Irene - Charlotte - Quinten -  Rani  | WAT WAT. (n.d.). https://www.watwat.be/op-kot/op-kot-gaan-vooral-ook-leren-balanceren-irene-charlotte-quinten-rani

Eenzaamheid bij studenten: ‘Het voelt alsof ik niets doe in mijn studententijd.’ (2025, April 14). Leef. https://www.cm.be/leef/werk-en-ontspanning/studeren/eenzaamheid-bij-studenten

## Bijlagen

- [Miro board](https://miro.com/welcomeonboard/WGEyZHZsblFZVGNXQVJNVzJKdk5OVTU5aWp1OWc3NWdFaFFhRjVIQWJWaE9md29yNUduek4rNlVRclVRUjNoTWRYelN0aWg1aE0xUUx5dSt2NmRVc3JYaXF3T1JYUUJSYko3e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)
- [Arduino code](https://github.com/WarreDV2004/UCD/tree/main/Interfaces)
- [Figma page](https://www.figma.com/design/PuCQlRo2D172Kp6RI2HuAu/Project-gebruiksgericht-ontwerpen?node-id=107-2)
- [STL-files](https://github.com/WarreDV2004/UCD/tree/main/NX_files_en_STL_files)

- Discovery
    - Enquête
        - [Enquête zelf](https://docs.google.com/forms/d/e/1FAIpQLSdTiTeYtFrR0ctaUDDQAj40V7SO8Fajl4KnH02I8rrvnsv31A/viewform?usp=pp_url)
        - [Protocol](https://docs.google.com/document/d/1A0FiS83AQZqOER-OXQ9g47Mbo12cE6BT3u4HJDeAB8g/edit?usp=sharing)
        - [Report](https://docs.google.com/document/d/1ouhfAIFP2HL8f6tUjhvbmpmvou1BWplHWs9gQeRJVTI/edit?usp=sharing)
    - Benchmark
        - [Protocol](https://docs.google.com/document/d/1Jy2eyoBW6n9cmcCh9hvYr_Qc-EFNRZidyvqS3wYgaU8/edit?usp=sharing)
        - [Report](https://docs.google.com/document/d/126ASfkEksQ4rDUWjOpNJmFLw9-Yusrcvi-pMoj0IQxg/edit?usp=sharing)

- Definition
  - Concept test
      - [Protocol](https://docs.google.com/document/d/1pN3SjwHLKOpVsttGDe6S51hZ9E7TkTI1/edit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)
      - [Report](https://docs.google.com/document/d/1ucsTmMfX84bAc7nFclVBQN54uENG8dV8cWng5rm5kpM/edit?usp=sharing)
  - User test
      - [Protocol](https://docs.google.com/document/d/1fZb_FDhLXpEABN7fJ9v1H8SrhXbhuXQO/edit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)
      - [Report](https://docs.google.com/document/d/15mQg2JderRjXdMa06qMra967utHhEO96udw502FnnFs/edit?usp=sharing)

- Develop
  - 1
    - [Protocol](https://docs.google.com/document/d/1r0aq8WSiM16s504EQ3FyjoloXnLYU9Ix3MpxWJum0ZM/edit?usp=sharing)
    - [Antropometrische studie](https://docs.google.com/document/d/151swEXQBkQlyvM8BVWTO21OE8UqdC8CK/edit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)
    - [Report](https://docs.google.com/document/d/1oeadrv8DQ0RTf0Ejnrk790tRzP5yXAQnDEZ7GdAOnDw/edit?usp=sharing)
  - 2
    - [Protocol gebruikers](https://docs.google.com/document/d/12B-Cmke9gG3i40l6qS__6FRIqVe_0yOZWLq1CjQbYws/edit?usp=sharing)
    - [Protocol kotbazen](https://docs.google.com/document/d/1rDKY6d_QxgnEzM0Auz7uWEix_a82Ln2P5h2jirHqcS0/edit?usp=sharing)
    - [Report gebruikers](https://docs.google.com/document/d/16a-wWIaQbUWTkn92t6JV0DqWhNdM8_EQYeHWOZipe1s/edit?usp=sharing)
    - [Report kotbazen](https://docs.google.com/document/d/1psnnQiBullsuw2VbTnilmwD4Vtc4XkxmrOvXDm3Nrhg/edit?usp=sharing)
  - 3
    - [Protocol](https://docs.google.com/document/d/1DAV1KiwxBQIpG94lSyFlZdrUHEIPZXJVJt8Hn87BGmM/edit?usp=sharing)
    - [Report](https://docs.google.com/document/d/1hrFZQWddpDQdi2w4NG7bEw3i99ifph0hlMxw7xFSaP4/edit?usp=sharing)

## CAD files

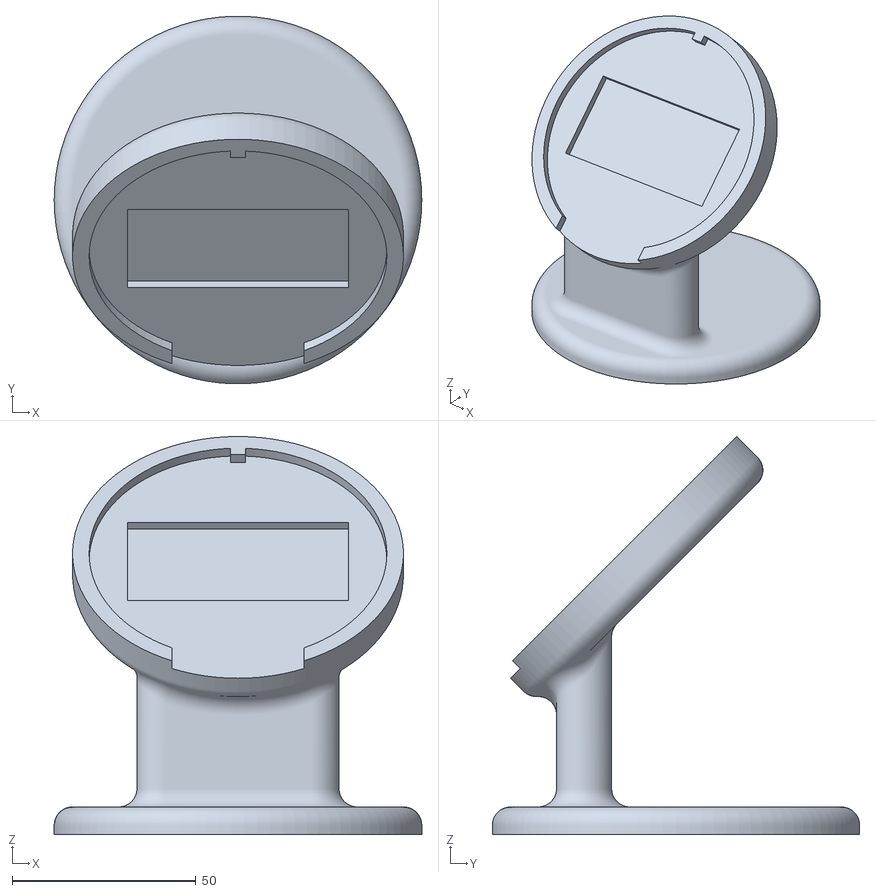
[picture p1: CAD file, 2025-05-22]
NX_files_en_STL_files/model_prototype_NX_en_STL/hub-show.stl
100.0 x 99.9 x 108.3

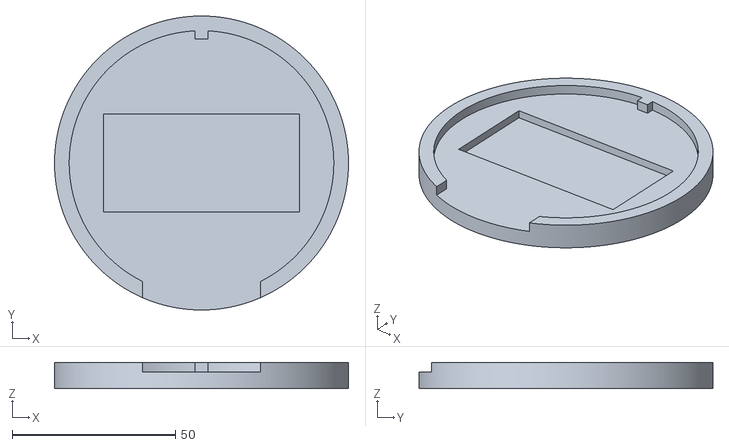
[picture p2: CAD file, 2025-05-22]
NX_files_en_STL_files/werkend_prototype_NX_en_STL/muurplaatje.stl
90.0 x 90.0 x 8.00

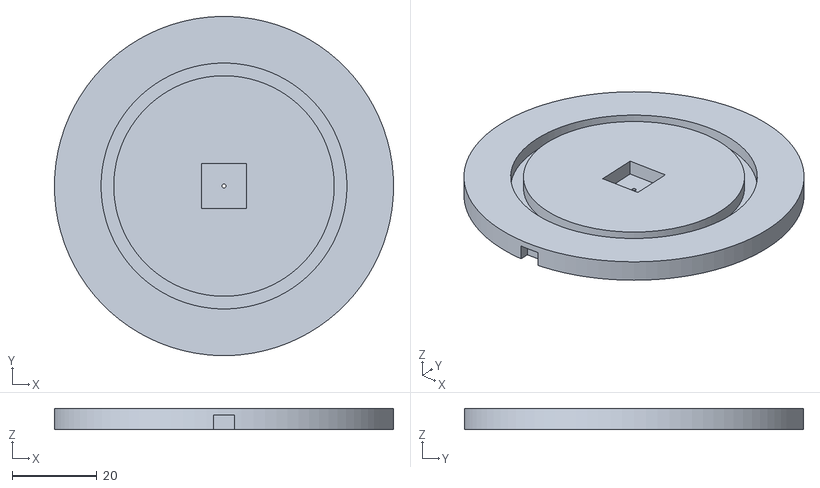
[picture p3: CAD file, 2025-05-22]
NX_files_en_STL_files/model_prototype_NX_en_STL/Achterkant.stl
80.0 x 80.0 x 5.00

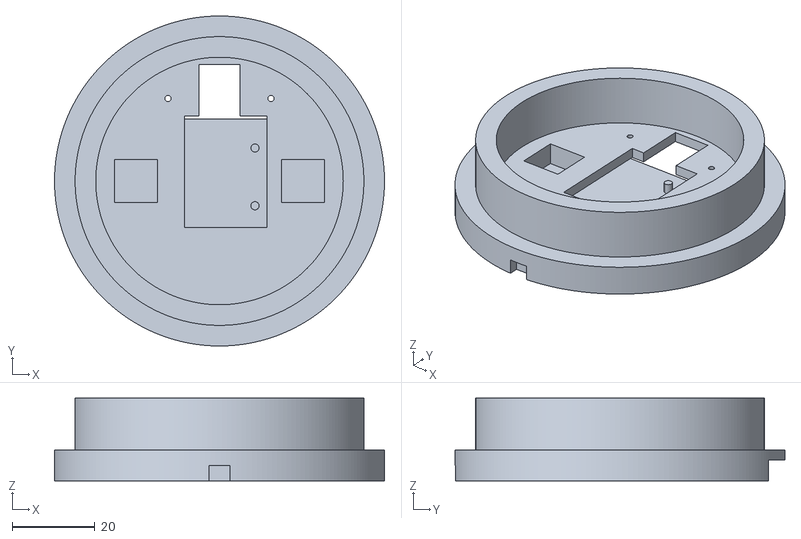
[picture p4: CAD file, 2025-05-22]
NX_files_en_STL_files/werkend_prototype_NX_en_STL/basis.stl
80.0 x 80.0 x 20.0

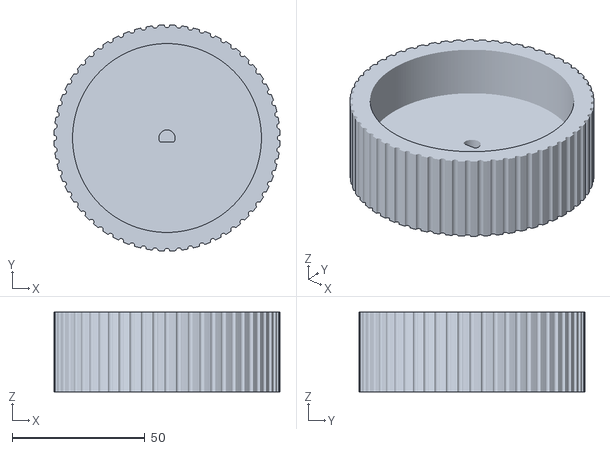
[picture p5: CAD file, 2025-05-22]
NX_files_en_STL_files/werkend_prototype_NX_en_STL/draaiwiel.stl
85.0 x 85.0 x 30.0

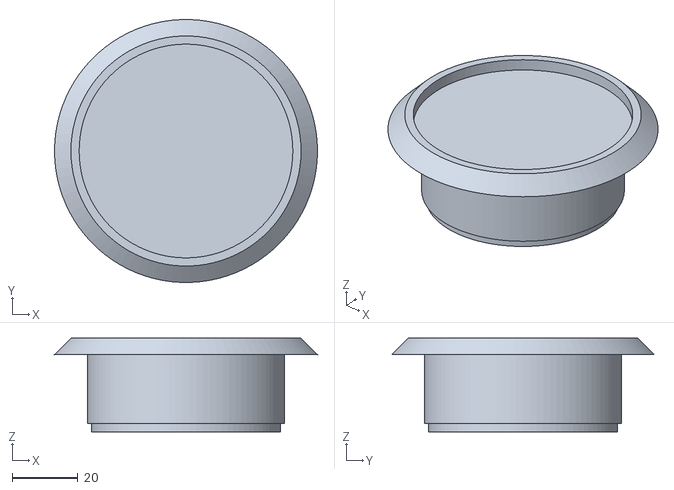
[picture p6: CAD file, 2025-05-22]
NX_files_en_STL_files/model_prototype_NX_en_STL/Middeldeel.stl
80.0 x 80.0 x 28.5

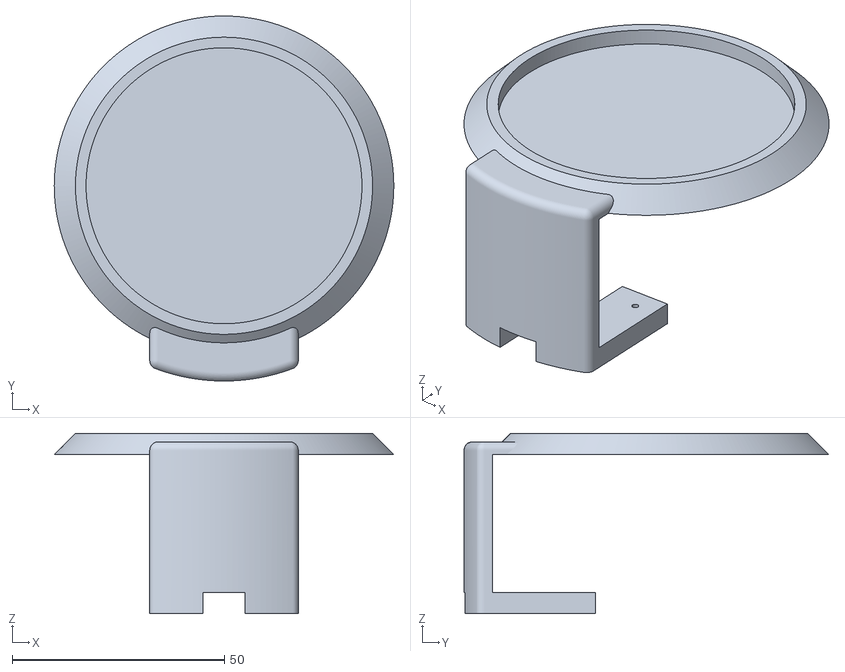
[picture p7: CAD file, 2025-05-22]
NX_files_en_STL_files/werkend_prototype_NX_en_STL/Bovenkant.stl
80.0 x 86.0 x 42.5

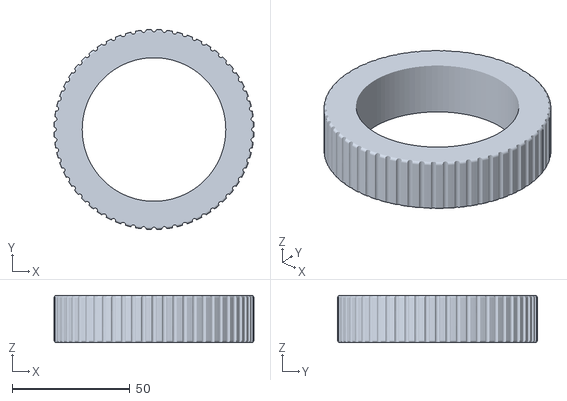
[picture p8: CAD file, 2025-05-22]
NX_files_en_STL_files/model_prototype_NX_en_STL/draaiwiel_show.stl
85.0 x 85.0 x 20.0

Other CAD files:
NX_files_en_STL_files/model_prototype_NX_en_STL/muurplaatje_show.stl
NX_files_en_STL_files/werkend_prototype_NX_en_STL/hub.stl
NX_files_en_STL_files/Exploded model_NX/batterij.prt
NX_files_en_STL_files/Exploded model_NX/bodemplaat.prt
NX_files_en_STL_files/Exploded model_NX/bovenplaat.prt
NX_files_en_STL_files/Exploded model_NX/condensator.prt
NX_files_en_STL_files/Exploded model_NX/draaiwiel.prt
NX_files_en_STL_files/Exploded model_NX/exploded view.prt
NX_files_en_STL_files/Exploded model_NX/glasplaatje.prt
NX_files_en_STL_files/Exploded model_NX/magneet.prt
NX_files_en_STL_files/Exploded model_NX/moederbord 1.prt
NX_files_en_STL_files/Exploded model_NX/printplaat.prt
NX_files_en_STL_files/Exploded model_NX/schakelaar.prt
NX_files_en_STL_files/Exploded model_NX/weerstand.prt
NX_files_en_STL_files/model_prototype_NX_en_STL/Achterkant.prt
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

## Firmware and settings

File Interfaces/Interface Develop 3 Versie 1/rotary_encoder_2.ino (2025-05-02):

//  Pin-definities
const int pinCLK = 3;       // Rotary encoder CLK (A)
const int pinDT = 4;        // Rotary encoder DT (B)
const int pinButton = 5;    // Drukknop op encoder
const int drukknop2 = 2;    // Tweede drukknop

//  Encoder variabelen
int encoderPos = 0;     
int encoderPosLast = 0;    
int lastCLKState;           
unsigned long lastEncoderTime = 0;  
const unsigned long encoderDebounceDelay = 100; 

//  Drukknop 1 (encoder) variabelen
int buttonPressCount = 0;   
bool lastButtonState = HIGH;
unsigned long lastDebounceTime = 0;
const unsigned long buttonDebounceDelay = 200;

//  Drukknop 2 variabelen
bool lastButtonState2 = HIGH;
unsigned long lastDebounceTime2 = 0;
const unsigned long buttonDebounceDelay2 = 200;

//  Nieuw: statusvariabele voor eerste drukknop bij buttonPressCount == 2
int drukknopStatus = 0;

void setup() {
    pinMode(pinCLK, INPUT);
    pinMode(pinDT, INPUT);
    pinMode(pinButton, INPUT_PULLUP);
    pinMode(drukknop2, INPUT_PULLUP);

    lastCLKState = digitalRead(pinCLK);
    lastButtonState = digitalRead(pinButton);
    lastButtonState2 = digitalRead(drukknop2);

    Serial.begin(9600);
}

void loop() {
    checkEncoder();  
    checkButton();   
    checkButton2();  
}

// 🔹 Controleer de rotary encoder (met debounce)
void checkEncoder() {
    int currentCLKState = digitalRead(pinCLK);

    if (currentCLKState != lastCLKState) {
        if (millis() - lastEncoderTime > encoderDebounceDelay) {
            int tempPos = encoderPos;

            if (digitalRead(pinDT) != currentCLKState) {
                tempPos++;  // Clockwise
            } else {
                tempPos--;  // Counterclockwise
            }

            if (buttonPressCount == 1) {
                if (tempPos >= -3 && tempPos <= 3) {
                    encoderPos = tempPos;
                }
            } else if (buttonPressCount == 4) {
                if (tempPos >= 0 && tempPos <= 16) {
                    encoderPos = tempPos;
                }
            } else if (buttonPressCount == 2) {
                if (tempPos >= 0 && tempPos <= 2) {
                    encoderPos = tempPos;
                } else if (tempPos < 0) {
                    encoderPos = 2;
                } else if (tempPos > 2){
                    encoderPos = 0;
                }
            } else {
                encoderPos = tempPos;
            }

            Serial.print("intensiteit||");
            Serial.println(encoderPos);
            lastEncoderTime = millis();
        }
    }

    lastCLKState = currentCLKState;
}

// 🔹 Controleer de drukknop op de encoder
void checkButton() {
    bool buttonState = digitalRead(pinButton);

    if (buttonState == LOW && lastButtonState == HIGH) {
        if (millis() - lastDebounceTime > buttonDebounceDelay) {
          if (buttonPressCount == 4 || buttonPressCount == 5) {
            buttonPressCount = 2;
          } 
          else {
            buttonPressCount++;
          }
            
            encoderPosLast = encoderPos;
            encoderPos = 0;
            Serial.print("drukken||");
            Serial.println(buttonPressCount);

            if (buttonPressCount == 3) {
                if (encoderPosLast == 0) {
                    buttonPressCount = 1;
                } else if (encoderPosLast == 1) {
                    buttonPressCount = 5;
                } else if (encoderPosLast == 2) {
                    buttonPressCount = 4;
                }
                Serial.print("drukken||");
                Serial.println(buttonPressCount);
            }

            lastDebounceTime = millis();
        }
    }

    lastButtonState = buttonState;
}

// 🔹 Controleer de tweede drukknop
void checkButton2() {
    bool currentButtonState2 = digitalRead(drukknop2);

    if (currentButtonState2 == LOW && lastButtonState2 == HIGH) {
        if (millis() - lastDebounceTime2 > buttonDebounceDelay2) {
            Serial.println("drukken2||1");
            lastDebounceTime2 = millis();
        }
    }

    lastButtonState2 = currentButtonState2;
}

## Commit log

2025-05-22 CAD files toegevoegd
    [Achterkant.prt, Achterkant.stl, Bovenkant.prt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]
2025-05-22 Arduino code en link naar figma toegevoegd
